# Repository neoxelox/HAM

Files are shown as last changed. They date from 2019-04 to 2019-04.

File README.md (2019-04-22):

# HAM
Home Automation and Monitoring System

Source Code for the 1st Award in Espressif / myDevices / Sparkfun contest: 
ESP8266 IoT Contest - Simplify the Connected World
- https://www.hackster.io/contests/ESP8266
- https://www.hackster.io/neoxelox/ham-home-automation-and-monitoring-system-930ad4

## Welcome to the definition of IoT, welcome to HAM. 

## INTRODUCTION 
HAM, Home Automatation and Monitoring system, is the result of the combination of 4 outstanding things: Cayenne, ESP8266, Arduino and Raspberry. 
The HAM network is formed by 5 different nodes and a central hub. However, thanks to the exclusive protocol inside of all the network, the HAM-PROTOCOL, can be expanded with more and more nodes. 
It also features an exclusive APP, using Cayenne API, which brings together sensors data and the video surveillance system.
## THE NODES 
There are 3 nodes, HAM-EXT (exterior), HAM-RDT (radiation) and HAM-GAS (gases), formed by all types of sensors. RDT and GAS, have gas sensors as Air Pollution, CO2, Natural Gas... which can affect heavily the duration of the battery, because of that, they are controlled by a transistor which the user can switch off/on. There is also the HAM-BLINDS node, which is the controller for the blinds. The last node is HAM-PEEPHOLE, which is a video surveillance system with vibration sensor, illuminance sensor and a loud alarm. The hub, HAM-HUB, is formed by a Sparkfun 8266 dev thing, temperature sensor, IR emitter, bluetooth, and in future updates it will feature a display in case internet access is down. The 3 node sensors have a built-in battery with charger, this allows to make them portable, and stick them in any surface. HAM-HUB is meant to be static, HAM-BLINDS is inside of a blind controller and HAM-PEEPHOLE is attached to a peephole, and it is also meant to be static because of the power consumption of the RPI 0 W. 
## CONNECTIVITY 
The connectivity of the HAM network is not only WiFi, actually only HAM-HUB has it, to send data values to cayenne, and also HAM-PEEPHOLE, where a camera surveillance server is hosted. HAM-EXT, HAM-GAS and HAM-RDT are connected to the hub via bluetooth, but how? Well, there are some BT modules that features piconet, which is a multi-slave bluetooth network. However, that things are $$$$, because of that, I decided to make my own false "piconet". Summarized, the proccess is a cycle for each BT module, divided in 3 parts: Connection, Gathering the sensors value and Disconnection. This is possible by entering the AT mode in a HC-05, and controlling the AT commands. This can seem tricky, but it actually made me end up making a hole protocol for all the nodes, which was a great idea. The protocol is named HAM-PROTOCOL, and it allows transfering, integer, float or string, information by the two ways in all my nodes, and it's more, I can make more nodes whenever I want, and putting them to the network in a few minutes. The protocol is explained in the codes of the nodes. However it looks like this:
- To request a value or a sensor or something:
<HAM-PROTOCOL,REQUEST>    
Example:  <HAM-PROTOCOL,batteryRDT.request> 
- To answer that request or send information:
<HAM-PROTOCOL,CHANNEL,INT_DATA,FLOAT_DATA,STRING_DATA>
Example:  
<HAM-PROTOCOL,batteryRDT,readBattery(),0,"0">
- Another example: Request and responses used in the cycle for the false piconet:
Connection:
Request:
<HAM-PROTOCOL,ready.request> 
Response:
<HAM-PROTOCOL,HAM-EXT,0,0,"OK-READY">
Gathering sensors data: Request and Response like in the examples.
Disconnection:
Request:
<HAM-PROTOCOL,HAM-EXT.requestAction.OFF> 
Response:
<HAM-PROTOCOL,HAM-EXT,0,0,"OK-OFF">
Finnaly, because HAM-BLINDS is inside of a little blind controller, it has to be very small, that's why I went for ATTINY85, and for the connectivity I decided IR using the HAM-PROTOCOL. 
## THE LIST OF SENSORS, ACTUATORS AND MORE, THAT EACH NODE HAS AND WHY 
### HAM-HUB
- TMP-36GZ: Temperature sensor. For room temperature.
- HC-SR501: IR Motion sensor. If anyone wants to touch the hub I will know...
- IR Emitter: To control HAM-BLINDS (or anything with IR).
- HC-05: In MASTER mode, to control all the Slaves.
### HAM-PEEPHOLE
- KY-01: Vibration sensor. It detects if anyone is entering or if the lock is being forced by burglars.
- LDR: Peephole darkness sensor. It detects if someone covers the peephole and blocks the video from the camera. As RPI 0 W doesn't have any analog inputs, it has a special circuit which RPI measures the time the capacitor takes to fill.
- Alarm: Loud alarm, borrowed from a old lego block I had, which RPI activates if the camera is blocked for 5 seconds, or if the vibrations are continuos.
- Webcam: Old webcam from a dead laptop. It can be any usb camera as RPI is using Motion script.
### HAM-BLINDS
- IR Receiver: To receive requests from HAM-HUB.
- Transistors: An ATTINY85 controls the motherboard of the blinds controller with transistors.
### HAM-EXT
- MQ 135: Air pollution sensor. God bless global warming!
- DHT11: Humidity/Temperature sensor. For exterior temperature/humidity.
- GY-91: Barometric pressure and altitude sensor, well altitude is not being measured (useless I think).
- KY-045: Rain sensor. It detects if it is raining / raining hard.
- LDR: Solar Illuminance sensor. Just take sun cream if this sensor says to you.
- UVM-30A: Solar UV sensor. High UV causes skin cancer.
- HC-06: Slave bluetooth for communication.
### HAM-RDT
- EMF Sensor: Electromagnetic field sensor. That radiation can cause cancer. This sensor is based on an antenna with a 3.3MOhm resistor.
- KY-05: Magnetic field sensor. Magnetic waves disturb our dreams.
- TSOP 34138: IR radiaton sensor. The atmosphere is pretty hot! Open the windows!
- SPARKFUN Electret MIC: You can already complain to your neighbor.
- HC-06: Slave bluetooth for communication.
### HAM-GAS
- MQ 2: CO2 sensor. CO2 is never good...
- MQ 5: Natural gas. At least my boiler works with it, so its good to detect any gas leak.
- MQ 6: Butane/Propane. Well I don't have a gas cooker, but my neighbors yes.
- MQ 7: CO is colorless, odorless, it doesn't taste, and last but not least it is letal.
- Thermistor: Temperature sensor. For Kitchen temperature (I run out of digital tmp sensors).
- KY-026: Fire sensor. Self-explanatory.
- HC-06: Slave bluetooth for communication.
## THE HAM APP 
It's in beta phase, so there is a bug with ham-gas displaying a "-", and the camera viewer works when it wants, but if I view it with chrome it works, I don't know why...
See https://www.hackster.io/neoxelox/ham-home-automation-and-monitoring-system-930ad4 for detailed images.
## CONCLUSION 
The nodes doesn't have an enclosure, which would be great, sadly I don't have a 3DPrinter, and I cannot use another material like wood, because of its weight. However, I have already experimented with 3D Modeling and I have made a sketch of how enclosures could be.

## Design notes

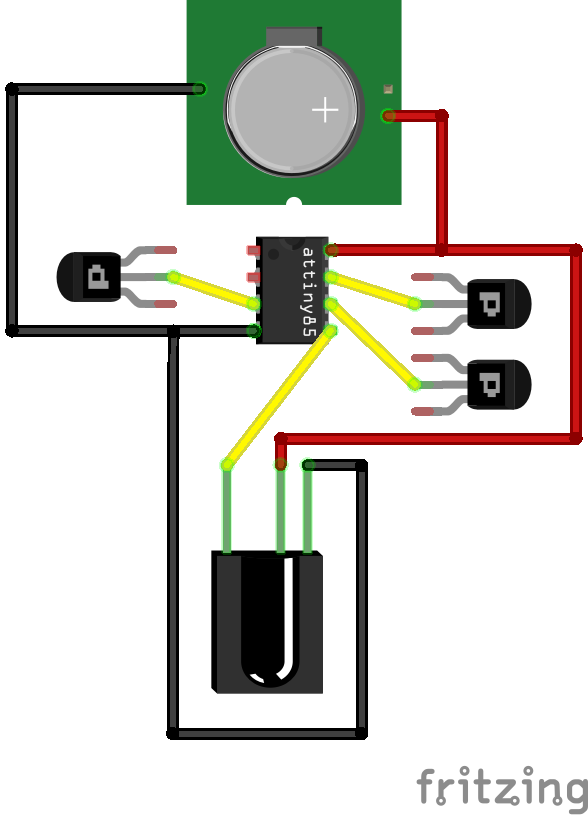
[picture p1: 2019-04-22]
schematics/HAM-BLINDS/ham-blinds_schematic.png

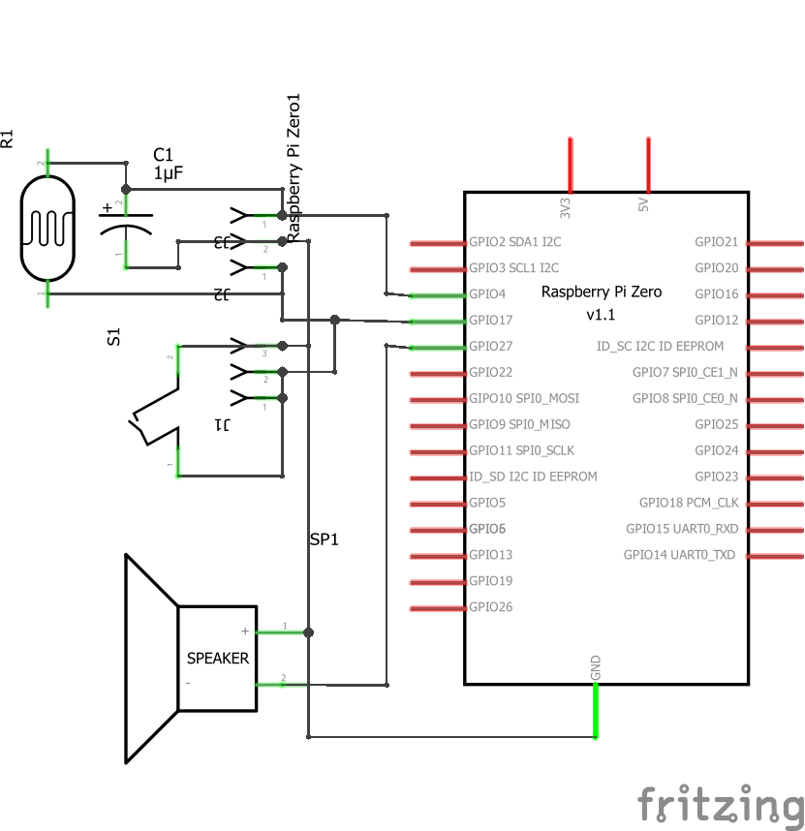
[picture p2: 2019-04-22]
schematics/HAM-PEEPHOLE/ham-peephole_schematic_root.png

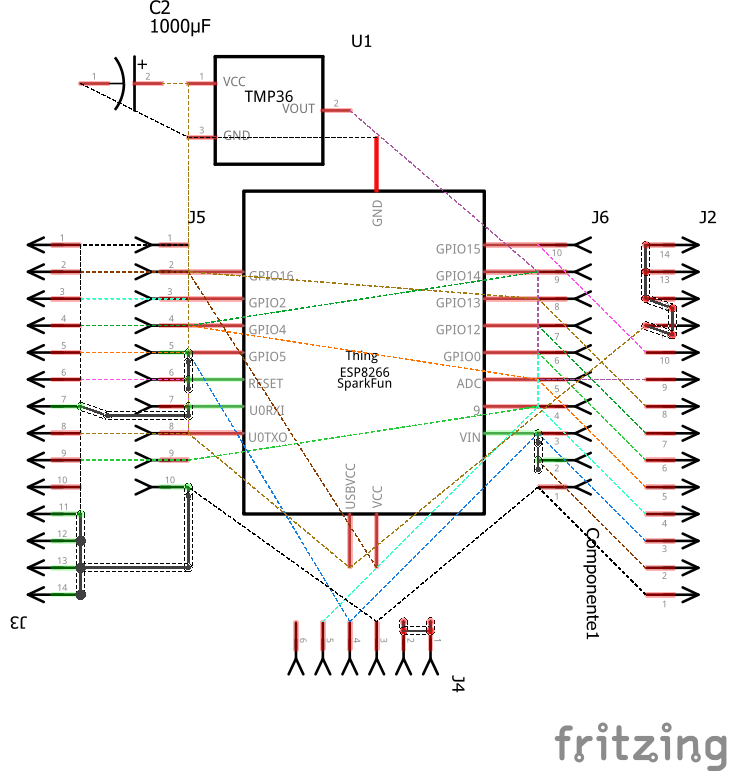
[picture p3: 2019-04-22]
schematics/HAM-HUB/ham-hub_schematic_root.png

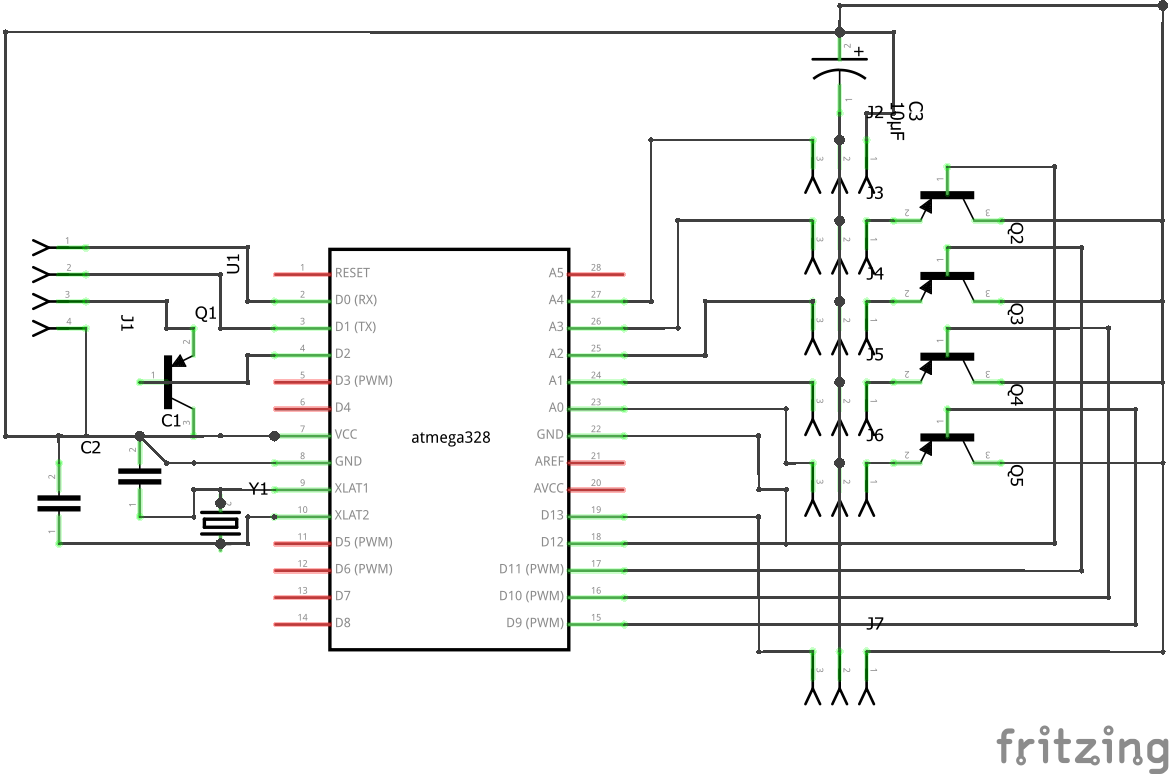
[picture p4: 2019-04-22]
schematics/HAM-GAS/ham-gas_schematic_root.png

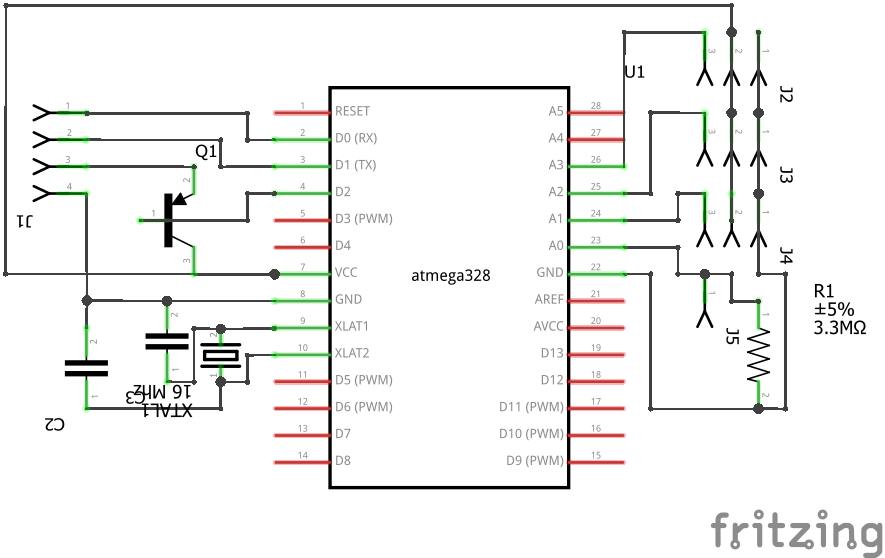
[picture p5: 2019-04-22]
schematics/HAM-RDT/ham-rdt_schematic_root.png

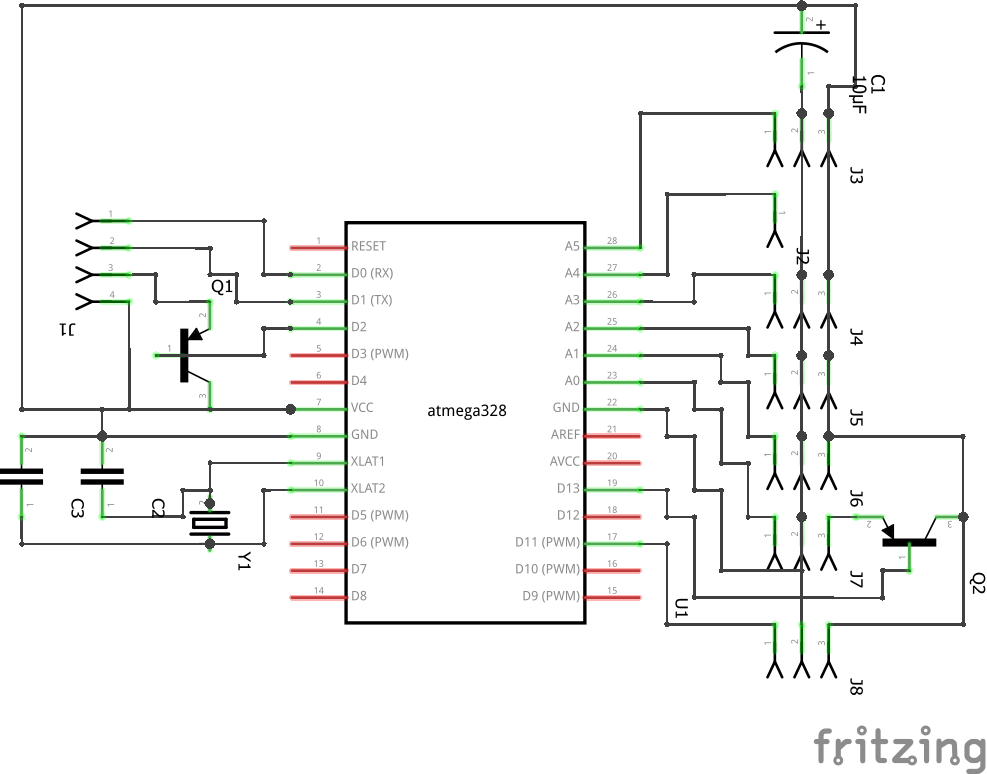
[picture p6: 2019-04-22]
schematics/HAM-EXT/ham-ext_schematic_root.png

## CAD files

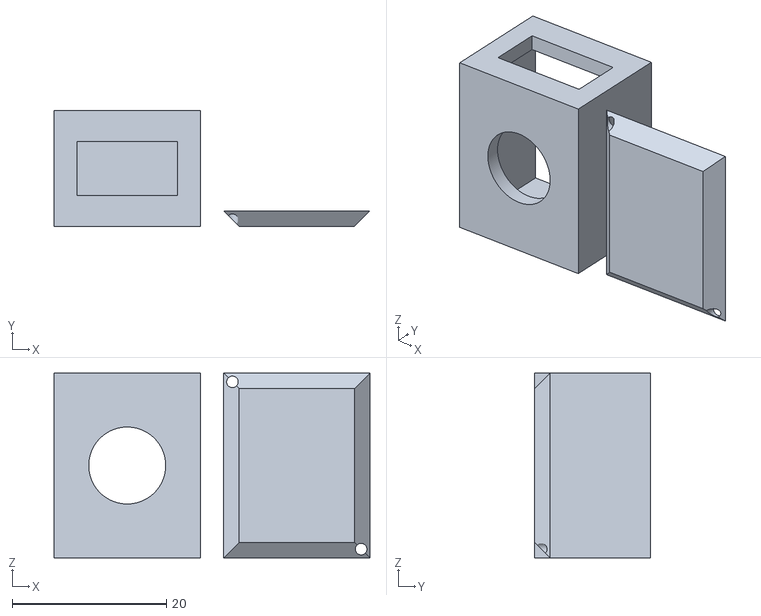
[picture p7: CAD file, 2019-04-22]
3Dmodels/ham-peephole-stl/ham-peephole.stl
41.0 x 15.0 x 24.0

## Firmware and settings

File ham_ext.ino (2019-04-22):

//  Exterior Sensors by @Neoxelox
//  Rev. 1 | Last modification: 12/10/2017

//  Libraries Section:

//  DHT11 Sensor
  #include <DHT.h>
  #include <DHT_U.h>

//  BMP280
  #include <Wire.h>
  #include "i2c.h"
  #include "i2c_BMP280.h"

//--------------\\  

//  Define Section:

  #define btPin 2   // Bluetooth Pin
  #define dhPin 11   // Humidity/Temperature Sensor Pin
  #define mqPin A0  // Air Pollution Sensor Pin
  #define smPin 13   // MQ135 Switch
  #define poPin A1  // Illuminance Sensor Pin
  #define rnPin A2  // Rain Sensor Pin
  #define uvPin A3  // UV Sensor Pin
  //BMP280 DEFINITIONS ARE DEFAULT 12C PINS A5/A4

//------------------\\

//  Variable Section:

//  Bluetooth
  int btTimeout = 3000; // Time that Bluetooth will be off after finishing transmitting data

//  DHT11 Sensor
  DHT dht11 (dhPin, DHT11); // Define the type of DHT (11)

// BMP280 Sensor
  BMP280 bmp280;  
  float pressure;
  static float altitude;

//  MQ135 Sensor
  #define mqSamples 50 // Samples from the sensor (More accurate)                                                         
  int mqArray[mqSamples];                    
  unsigned long mqAverage;
  #define mqNoPol 500 // Calibrated data where there is not Pollution
  int mqValue;

//  Illuminance Sensor
  #define alfaIllu 0.0048828125 // Alfa calibrated for unit of lux

//  Rain Sensor
  int rainRaw, rainVal;

//  UV Sensor
  int uvVoltage = 0;
  int uvIndex = 0;    

//  Battery
  long battery;  

//  HAM PROTOCOL  
  const byte numChars = 64;
  char receivedChars[numChars];
  char tempChars[numChars]; // Temporary array for use when parsing

//  Variables to hold the parsed data
  String BT_REQUEST, messageFromBTplaceHolder, BT_PROTOCOL;
  boolean newData = false;

//----------------------\\


void setup() 
{

//  Bluetooth
  pinMode(btPin, OUTPUT);
  digitalWrite(btPin, HIGH);  // Power on Bluetooth via transistor
  delay(100);
  Serial.begin(9600); // Prepare communication through BT

//  DHT11 Sensor
  dht11.begin();  // Begin DHT11

//  MQ135 Sensor
  pinMode(mqPin, INPUT);  // Prepare pin to receive data
  pinMode(smPin, OUTPUT);
  digitalWrite(smPin, HIGH); // Power on MQ135 via transistor

//  Illuminance Sensor
  pinMode(poPin, INPUT);  // Prepare pin to receive data

//  Rain Sensor
  pinMode(rnPin, INPUT);  // Prepare pin to receive data  

//  UV Sensor
  pinMode(uvPin, INPUT);  // Prepare pin to receive data

//  BMP280 Sensor
  bmp280.initialize();
  bmp280.setEnabled(0);
  bmp280.triggerMeasurement();   
  
}

void loop()
{

  receiveHAMProtocol();
  if (newData == true) 
  {
    
    strcpy(tempChars, receivedChars); // Temporary copy to protect the original data for later manipulation
    
    if (parseData() == true)
    
    {
      
      manipulateData();
      
    }
   
    newData = false;
   
   }
  
}

void btRestart()  // Restarts the Bluetooth after transmitting data
{
  digitalWrite(btPin, LOW);
  delay(btTimeout);
  digitalWrite(btPin, HIGH);
  delay(100);
}

int readIl()  // Reads the Illuminance
{
  return((2500/(analogRead(poPin)*alfaIllu)-500)/10);  
}

int readMq()  // Reads the concentration of Pollution
{
  for(int i = 0; i < mqSamples; i++)
  {              
  mqArray[i] = analogRead(mqPin);      
  mqAverage += mqArray[i];  
  }
                
  mqValue = mqAverage / mqSamples;                  
  mqValue = map(mqValue, mqNoPol, 1023, 0, 100);                                                    
  mqAverage = 0;    
  return(mqValue);              
}

int readRn()  // Reads the Rain
{
  rainRaw = analogRead(rnPin);
  if(rainRaw <=1023)
  {
    rainVal = 1;
  }else if(rainRaw >= 1024 && rainRaw <= 8000)
  {
    rainVal = 2;
  }else if(rainRaw > 8000)
  {
    rainVal = 3;
  }

  return(rainVal);
}

int readUv()  // Reads the UV Index
{
  uvVoltage = (analogRead(uvPin) * (5.0 / 1023.0)) * 1000;
  if(uvVoltage<227){
    uvIndex = 0;
  }
  if(uvVoltage>=227){
    uvIndex = 1;
  }
  if(uvVoltage>=318){
    uvIndex = 2;
  }
  if(uvVoltage>=408){
    uvIndex = 3;
  }
  if(uvVoltage>=503){
    uvIndex = 4;
  }
  if(uvVoltage>=606){
    uvIndex = 5;
  }
  if(uvVoltage>=669){
    uvIndex = 6;
  }
  if(uvVoltage>=795){
    uvIndex = 7;
  }
  if(uvVoltage>=881){
    uvIndex = 8;
  }
  if(uvVoltage>=976){
    uvIndex = 9;
  }
  if(uvVoltage>=1079){
    uvIndex = 10;
  }
  if(uvVoltage>=1170){
    uvIndex = 11;
  }
  return(uvIndex);
}

float readPressure() // Reads the pressure
{
  bmp280.awaitMeasurement();
  bmp280.getPressure(pressure);
  bmp280.triggerMeasurement();

  return(pressure);
}

float readAltitude() // Reads the altitude
{
  bmp280.awaitMeasurement();
  bmp280.getAltitude(altitude);
  bmp280.triggerMeasurement();

  return(altitude);
}

long readBattery()  // Reads the battery percent
{
ADMUX = _BV(REFS0) | _BV(MUX3) | _BV(MUX2) | _BV(MUX1); 
delay(2); // Wait for Vref to settle
ADCSRA |= _BV(ADSC);  // Convert
while (bit_is_set(ADCSRA,ADSC)); 
battery = ADCL;
battery |= ADCH<<8; 
battery = 1126400L / battery; // Back-calculate AVcc in mV
return (map(battery, 4500, 5000, 0, 100)); 
}

void receiveHAMProtocol() // Receives the message via HAM PROTOCOL
{
    static boolean recvInProgress = false;
    static byte ndx = 0;
    char startMarker = '<';
    char endMarker = '>';
    char rc;

    while (Serial.available() > 0 && newData == false) 
    {
        rc = Serial.read();

        if (recvInProgress == true) 
        {
            if (rc != endMarker) // Searchs for the endMarker
            {
                receivedChars[ndx] = rc;
                ndx++;
                if (ndx >= numChars) 
                {
                    ndx = numChars - 1;
                }
            }
            else 
            {
                receivedChars[ndx] = '\0'; // Terminate the string
                recvInProgress = false;
                ndx = 0;
                newData = true;
            }
        }

        else if (rc == startMarker) // Searchs for the startMarker
        {
            recvInProgress = true;
        }
    }
}

String buildHAMProtocol(String channelName, int intData, float floatData, String stringData)  // Constructs the necessary HAM protocol to send
{
  
  return("<HAM-PROTOCOL,"+ channelName + "," + String(intData) + "," + String(floatData) + "," + stringData + ">");
  
}

boolean parseData() // Splits the data into its parts --> Expects <HAM-PROTOCOL, request>
{      

    boolean correctProtocol;  // Boolean var to store if the readed protocol is the correct one
    char * strtokIndx;  // This is used by strtok() as an index

    // EXPECTED FIRST PART: THE HAM PROTOCOL

    strtokIndx = strtok(tempChars,","); // Gets the first part (a String)
     
    messageFromBTplaceHolder += strtokIndx;    
    BT_PROTOCOL = messageFromBTplaceHolder;   
    messageFromBTplaceHolder = "";

    if (BT_PROTOCOL == "HAM-PROTOCOL"){correctProtocol = true;} else {correctProtocol = false;}

    //======================================

    // EXPECTED SECOND PART: THE REQUEST
    
    strtokIndx = strtok(NULL, ","); // Gets the second part (a String)
    
    messageFromBTplaceHolder += strtokIndx;    
    BT_REQUEST = messageFromBTplaceHolder;   
    messageFromBTplaceHolder = "";

    //=====================================

    return correctProtocol; // Returns true if the protocol used was HAM-PROTOCOL

} 

void manipulateData() // Manipulates the data received and parsed
{

    // COMMAND ZONE =========================================    
    
    if (BT_REQUEST == "ready.request") /*-->*/ {Serial.println(buildHAMProtocol("HAM-EXT", 0, 0, "OK-READY"));}
    if (BT_REQUEST == "HAM-EXT.requestAction.OFF") /*-->*/ {Serial.println(buildHAMProtocol("HAM-EXT", 0, 0, "OK-OFF")); delay(250); /*-->*/ btRestart();}
    if (BT_REQUEST == "batteryEXT.request") /*-->*/ {Serial.println(buildHAMProtocol("batteryEXT", readBattery(), 0, "0"));}
    if (BT_REQUEST == "airpol.requestData") /*-->*/ {Serial.println(buildHAMProtocol("airpol", readMq(), 0, "0"));}
    if (BT_REQUEST == "exteriortemp.requestData") /*-->*/ {Serial.println(buildHAMProtocol("exteriortemp", 0, dht11.readTemperature(), "0"));}
    if (BT_REQUEST == "humidity.requestData") /*-->*/ {Serial.println(buildHAMProtocol("humidity", 0, dht11.readHumidity(), "0"));}
    if (BT_REQUEST == "illuminance.requestData") /*-->*/ {Serial.println(buildHAMProtocol("illuminance", readIl(), 0, "0"));}
    if (BT_REQUEST == "rain.requestData") /*-->*/ {Serial.println(buildHAMProtocol("rain", readRn(), 0, "0"));}
    if (BT_REQUEST == "uvrad.requestData") /*-->*/ {Serial.println(buildHAMProtocol("uvrad", readUv(), 0, "0"));}
    if (BT_REQUEST == "pressure.requestData") /*-->*/ {Serial.println(buildHAMProtocol("pressure", 0, readPressure(), "0"));}
    if (BT_REQUEST == "altitude.requestData") /*-->*/ {Serial.println(buildHAMProtocol("altitude", 0, readAltitude(), "0"));}
   
    if (BT_REQUEST == "airpol.requestAction.OFF") /*-->*/ {Serial.println(buildHAMProtocol("airpol", 0, 0, "OK-OFF")); /*-->*/ digitalWrite(smPin, LOW);}
    if (BT_REQUEST == "airpol.requestAction.ON") /*-->*/ {Serial.println(buildHAMProtocol("airpol", 0, 0, "OK-ON")); /*-->*/ digitalWrite(smPin, HIGH);}
    
    //=======================================================
    
}

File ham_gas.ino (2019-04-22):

//  Gases Sensor by @Neoxelox
//  Rev. 1 | Last modification: 12/10/2017

//  Define Section:

  #define btPin 2   // Bluetooth Pin
  #define m2Pin A0  // CO2 Gas Sensor Pin
  #define s2Pin 11   // MQ2 Switch
  #define m5Pin A1  // Natural Gas Sensor Pin
  #define s5Pin 9   // MQ5 Switch
  #define m6Pin A2  // Butane/Propane Gas Sensor Pin
  #define s6Pin 10   // MQ6 Switch
  #define m7Pin A3  // CO Gas Sensor Pin
  #define s7Pin 12   // MQ7 Switch
  #define flPin 13   // Flame Sensor Pin
  #define tpPin A4  // Temperature Sensor Pin

//------------------\\

//  Variable Section:

//  Bluetooth
  int btTimeout = 3000; // Time that Bluetooth will be off after finishing transmitting data

//  MQ2 Sensor
  #define m2Samples 50 // Samples from the sensor (More = More accurate but less SRAM)                                                         
  int m2Array[m2Samples];                    
  unsigned long m2Average;
  #define m2NoGas 500 // Calibrated data where there is not Gas
  int m2Value;

//  MQ5 Sensor
  #define m5Samples 50 // Samples from the sensor (More = More accurate but less SRAM)                                                         
  int m5Array[m5Samples];                    
  unsigned long m5Average;
  #define m5NoGas 500 // Calibrated data where there is not Gas
  int m5Value;

//  MQ6 Sensor
  #define m6Samples 50 // Samples from the sensor (More = More accurate but less SRAM)                                                         
  int m6Array[m6Samples];                    
  unsigned long m6Average;
  #define m6NoGas 500 // Calibrated data where there is not Gas
  int m6Value;

//  MQ7 Sensor
  #define m7Samples 50 // Samples from the sensor (More = More accurate but less SRAM)                                                         
  int m7Array[m7Samples];                    
  unsigned long m7Average;
  #define m7NoGas 500 // Calibrated data where there is not Gas
  int m7Value;    
  
//  Temperature Sensor
  #define tpMin 0 // Calibrated data where there is the minimun temperature
  #define tpMax 95.46 // Calibrated data where there is the maximum temperature

//  Battery
  long battery;  

//  HAM PROTOCOL  
  const byte numChars = 64;
  char receivedChars[numChars];
  char tempChars[numChars]; // Temporary array for use when parsing

// Variables to hold the parsed data
  String BT_REQUEST, messageFromBTplaceHolder, BT_PROTOCOL;
  boolean newData = false;

//----------------------\\


void setup() 
{

//  Bluetooth
  pinMode(btPin, OUTPUT);
  digitalWrite(btPin, HIGH);  // Power on Bluetooth via transistor
  delay(100);
  Serial.begin(9600); // Prepare communication through BT

//  MQ2 Sensor
  pinMode(m2Pin, INPUT);  // Prepare pin to receive data
  pinMode(s2Pin, OUTPUT);
  digitalWrite(s2Pin, HIGH); // Power on MQ2 via transistor

//  MQ5 Sensor
  pinMode(m5Pin, INPUT);  // Prepare pin to receive data
  pinMode(s5Pin, OUTPUT);
  digitalWrite(s5Pin, HIGH); // Power on MQ5 via transistor

//  MQ6 Sensor
  pinMode(m6Pin, INPUT);  // Prepare pin to receive data
  pinMode(s6Pin, OUTPUT);
  digitalWrite(s6Pin, HIGH); // Power on MQ6 via transistor

//  MQ7 Sensor
  pinMode(m7Pin, INPUT);  // Prepare pin to receive data
  pinMode(s7Pin, OUTPUT);
  digitalWrite(s7Pin, HIGH); // Power on MQ7 via transistor    
  
//  Flame Sensor
  pinMode(flPin, INPUT);  // Prepare pin to receive data

//  Temperature Sensor  
  pinMode(tpPin, INPUT);  // Prepare pin to receive data
  
}

void loop()
{

  receiveHAMProtocol();
  if (newData == true) 
  {
    
    strcpy(tempChars, receivedChars); // Temporary copy to protect the original data for later manipulation
    
    if (parseData() == true)
    
    {
      
      manipulateData();
      
    }
   
    newData = false;
   
   }
  
}

void btRestart()  // Restarts the Bluetooth after transmitting data
{
  digitalWrite(btPin, LOW);
  delay(btTimeout);
  digitalWrite(btPin, HIGH);
  delay(100);
}

float readTp()  // Reads the Temperature
{
  return(map(analogRead(tpPin), 0, 1023, tpMin, tpMax));  
}

int readM2()  // Reads the concentration of CO2 Gas
{
  for(int i = 0; i < m2Samples; i++)
  {              
  m2Array[i] = analogRead(m2Pin);      
  m2Average += m2Array[i];  
  }
                
  m2Value = m2Average / m2Samples;                  
  m2Value = map(m2Value, m2NoGas, 1023, 0, 100);                                                    
  m2Average = 0;    
  return(m2Value);              
}

int readM5()  // Reads the concentration of Natural Gas
{
  for(int i = 0; i < m5Samples; i++)
  {              
  m5Array[i] = analogRead(m5Pin);      
  m5Average += m5Array[i];  
  }
                
  m5Value = m5Average / m5Samples;                  
  m5Value = map(m5Value, m5NoGas, 1023, 0, 100);                                                    
  m5Average = 0;    
  return(m5Value);              
}

int readM6()  // Reads the concentration of Butane/Propane Gas
{
  for(int i = 0; i < m6Samples; i++)
  {              
  m6Array[i] = analogRead(m6Pin);      
  m6Average += m6Array[i];  
  }
                
  m6Value = m6Average / m6Samples;                  
  m6Value = map(m6Value, m6NoGas, 1023, 0, 100);                                                    
  m6Average = 0;    
  return(m6Value);              
}

int readM7()  // Reads the concentration of CO Gas
{
  for(int i = 0; i < m7Samples; i++)
  {              
  m7Array[i] = analogRead(m7Pin);      
  m7Average += m7Array[i];  
  }
                
  m7Value = m7Average / m7Samples;                  
  m7Value = map(m7Value, m7NoGas, 1023, 0, 100);                                                    
  m7Average = 0;    
  return(m7Value);              
}

long readBattery()  // Reads the battery percent
{
ADMUX = _BV(REFS0) | _BV(MUX3) | _BV(MUX2) | _BV(MUX1); 
delay(2); // Wait for Vref to settle
ADCSRA |= _BV(ADSC);  // Convert
while (bit_is_set(ADCSRA,ADSC)); 
battery = ADCL;
battery |= ADCH<<8; 
battery = 1126400L / battery; // Back-calculate AVcc in mV
return (map(battery, 4500, 5000, 0, 100)); 
}
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
